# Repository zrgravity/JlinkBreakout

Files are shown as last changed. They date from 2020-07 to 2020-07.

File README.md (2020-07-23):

# JlinkBreakout

Segger Jlink to Tag-Connect/SWD breakout board.

## [V2](V2/)
Notes:
 - Use a right-angle 2 row, 20 position 0.1" (2.54mm) female header/socket
     + https://lcsc.com/product-detail/Pin-Header-Female-Header_Ckmtw-Shenzhen-Cankemeng-C124406_C124406.html

## [V3](V3/)
- Adds a voltage regulator with selectable output voltage (3.3V, 2.5V, 1.8V, External power)
- JST-XH connector for SWD
- 2x3 IDC Tag-connect header
- JTAG connector is standard 2 row, 20 position 0.1" (2.54mm) female header/socker, mounted on pcb edge
    + https://lcsc.com/product-detail/Pin-Header-Female-Header_BOOMELE-Boom-Precision-Elec-C30867_C30867.html
        * Pin thickness: 0.32mm to .064mm
        * Pin-pin clearance: 2.22mm to 1.9mm
    + Standard 1.6mm (0.062") PCB should be solderable, but there will be a small gap, or 2mm (0.079") PCB would leave less clearance

## [V3 - wire pads](/V3-wire-pads/)
- Solder jumpers to select voltage regulator output voltage
- Wire solderable edge connection for SWD
    + Also compatible with standard 0.1" headers
- Connector for power input to DUT (or access to output from regulator)
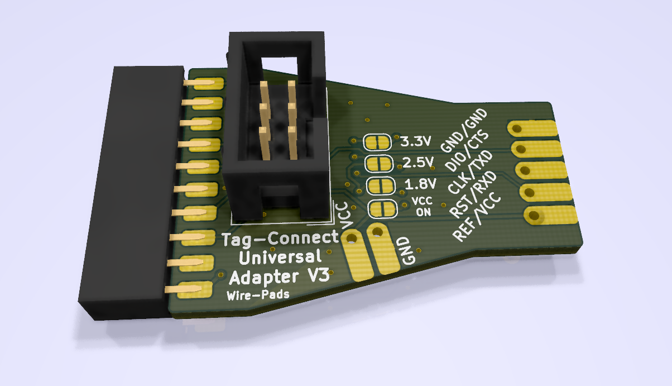
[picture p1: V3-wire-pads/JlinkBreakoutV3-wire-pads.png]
V3 - wire pads


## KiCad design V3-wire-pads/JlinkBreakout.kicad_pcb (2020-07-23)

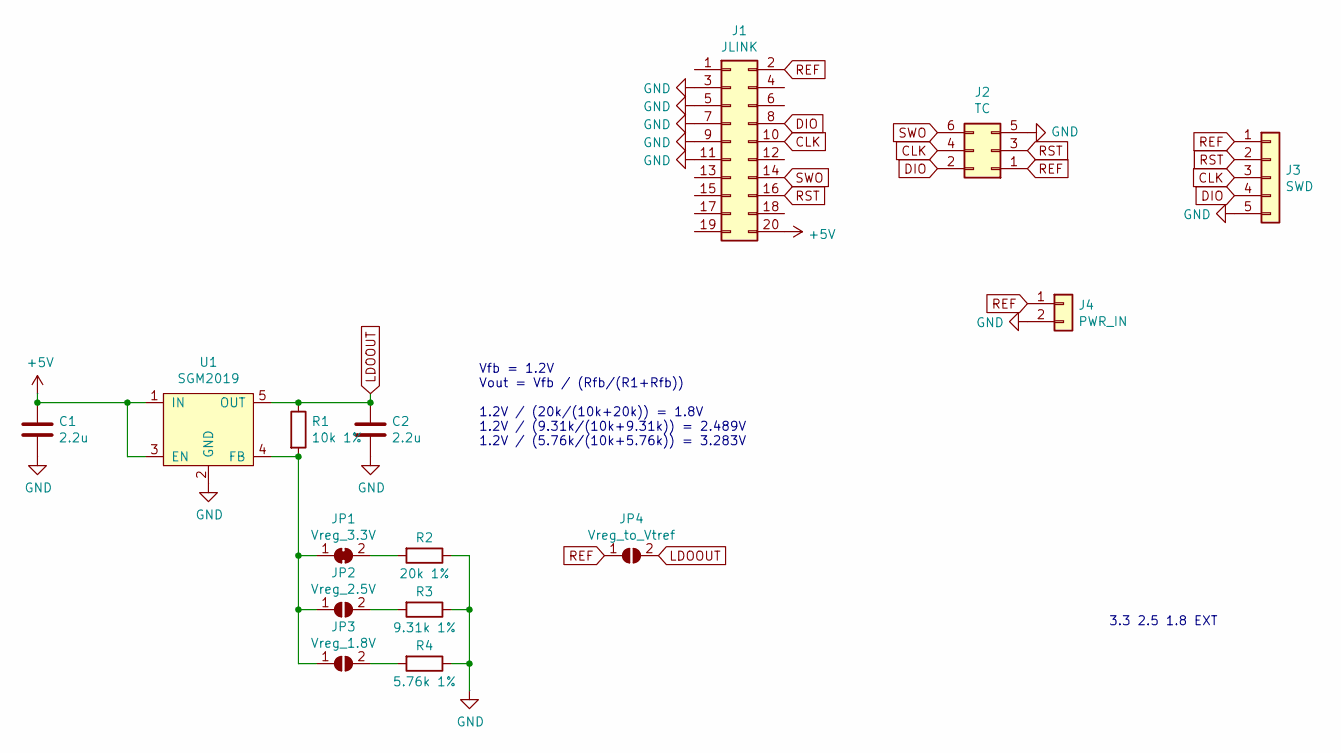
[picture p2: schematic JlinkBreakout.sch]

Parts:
C1: 2.2u; C_0805_2012Metric; LCSC C49217
C2: 2.2u; C_0805_2012Metric
J1: JLINK; conn_02x10_edge; LCSC C30867
J2: TC; IDC-Header_2x03_P2.54mm_Vertical; LCSC C11214
J3: SWD; conn_edge_PTH_2.54mm_2x5_05; LCSC C161872
J4: PWR_IN; conn_edge_PTH_2.54mm_2x5_02
JP1: Vreg_3.3V; SolderJumper-2_P1.3mm_Bridged_RoundedPad1.0x1.5mm
JP2: Vreg_2.5V; SolderJumper-2_P1.3mm_Open_RoundedPad1.0x1.5mm
JP3: Vreg_1.8V; SolderJumper-2_P1.3mm_Open_RoundedPad1.0x1.5mm
JP4: Vreg_to_Vtref; SolderJumper-2_P1.3mm_Open_RoundedPad1.0x1.5mm
R1: 10k 1%; R_0603_1608Metric; LCSC C25804
R2: 20k 1%; R_0603_1608Metric
R3: 9.31k 1%; R_0603_1608Metric
R4: 5.76k 1%; R_0603_1608Metric
U1: SGM2019; SOT-23-5; LCSC C24330

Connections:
+5V: C1.1, J1.20, U1.1 (IN), U1.3 (EN)
CLK: J1.10, J2.4, J3.3
DIO: J1.8, J2.2, J3.4
GND: C1.2, C2.2, J1.3, J1.5, J1.7, J1.9, J1.11, J2.5, J3.5, J4.2, R2.1, R3.1, R4.1, U1.2 (GND)
LDOOUT: C2.1, JP4.2 (B), R1.1, U1.5 (OUT)
unnamed: JP1.1 (A), JP2.1 (A), JP3.1 (A), R1.2, U1.4 (FB)
unnamed: JP1.2 (B), R2.2
unnamed: JP2.2 (B), R3.2
unnamed: JP3.2 (B), R4.2
REF: J1.2, J2.1, J3.1, J4.1, JP4.1 (A)
RST: J1.16, J2.3, J3.2
SWO: J1.14, J2.6

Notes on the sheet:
3.3 2.5 1.8 EXT
Vfb = 1.2V Vout = Vfb / (Rfb/(R1+Rfb)) 1.2V / (20k/(10k+20k)) = 1.8V 1.2V / (9.31k/(10k+9.31k)) = 2.489V 1.2V / (5.76k/(10k+5.76k)) = 3.283V

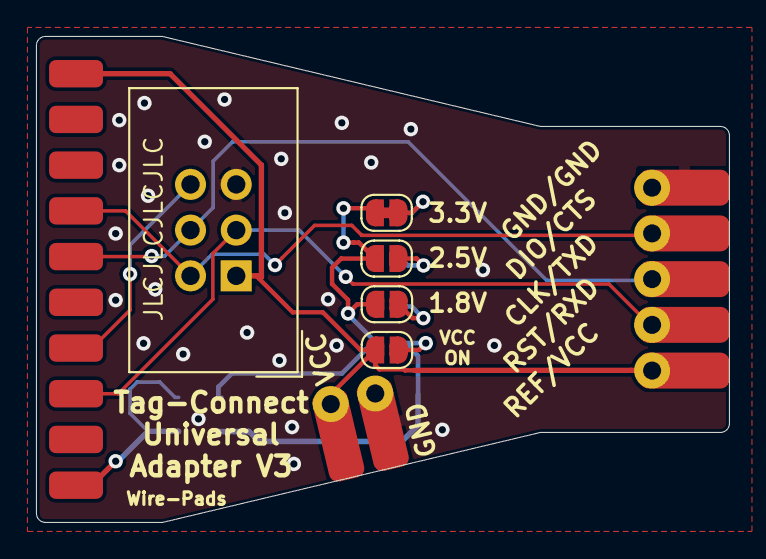
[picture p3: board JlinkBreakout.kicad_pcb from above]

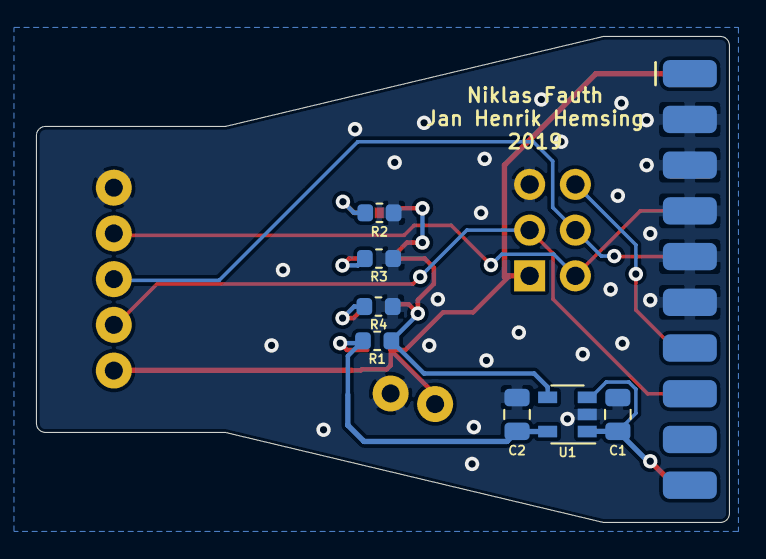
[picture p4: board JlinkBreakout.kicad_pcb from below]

Board: 2 copper layers, 38.5 x 27.0 mm, 15 parts (7 on the bottom side), 12 nets.

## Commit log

2020-07-23 V3-wire pads: create, replace switch with solder jumpers, connector
    [JlinkBreakout.kicad_pcb, JlinkBreakout.sch]
2020-07-23 Route v3-wire pads PCB, add to README
    Uses solder jumpers to select voltage, external power input/output pads
    [JlinkBreakout.kicad_pcb, JlinkBreakout.sch]
2020-07-23 Rename folder and image to fix README
    [JlinkBreakout.kicad_pcb, JlinkBreakout.sch]
2020-07-23 Backup footprints
2020-07-23 Add LCSC part numbers to resistors
    [JlinkBreakout.sch]
2020-07-23 Ignore gerber files
    Should go in releases instead
